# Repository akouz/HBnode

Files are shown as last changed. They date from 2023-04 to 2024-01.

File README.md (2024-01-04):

# HBnode
Microcontroller boards for [HBus](https://github.com/akouz/HBus) based on [AVR64DD32](https://www.microchip.com/en-us/product/avr64dd32). Form factor is the same as Arduino Pro Mini and Arduino Nano, while pinout made as close as possible. Firmware update made using on-board I2C EEPROM; custom bootloader occupies 1K bytes. 

[Programmer HEXloader.exe](https://github.com/akouz/HBnode/tree/main/AVR64DD32/Programmer/Software) can transfer compiled hex files from PC to EEPROM via Arduino UNO running [sketch HEXloader.ino](https://github.com/akouz/HBnode/tree/main/AVR64DD32/Programmer/Sketch). When a board used in HBus network, firmware can be updated remotely via HBus.

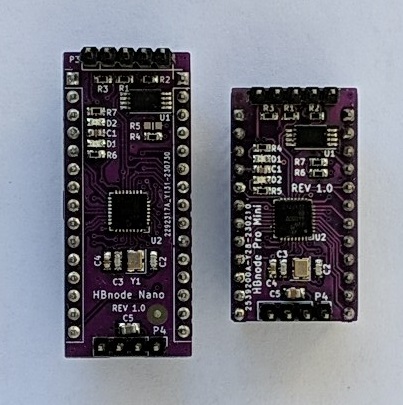
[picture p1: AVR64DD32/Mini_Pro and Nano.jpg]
Pro Mini and Nano


# How to program HBnode board:
1. Burn bootloader. 
   Plug PicKit4 to 4-pin connector, apply power to the board and burn [HBnode bootloader](https://github.com/akouz/HBnode/blob/main/AVR64DD32/Bootloader) using MPLAB.X IDE or MPLAB.X IPE.

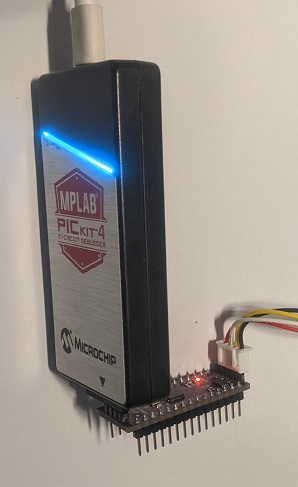
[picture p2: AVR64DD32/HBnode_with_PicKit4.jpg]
HBnode with PicKit4


2. Load HBus sketch.
   Connect HBnode to the [programmer](https://github.com/akouz/HBnode/tree/main/AVR64DD32/Programmer) and transfer selected sketch to the HBnode using [HEXLoader](https://github.com/akouz/HBnode/tree/main/AVR64DD32/Programmer/Software)
   
3. When a correct sketch is programmed to the HBnode, a new sketch can be loaded to the board via HBus using [NodeTest](https://github.com/akouz/HBus/tree/master/NodeTest)

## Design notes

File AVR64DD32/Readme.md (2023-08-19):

# HBnode AVR64DD32

Small modules based on AVR64DD32 are supposed to be used in [HBus](https://github.com/akouz/HBus) project instead of Arduino Pro Mini and Arduino Nano. They have the same size and similar pin-out, but differs by the following:

-- Program memory 64K instead of 32K.

-- Clock frequency 24 MHz instead of 16 MHz

-- Custom made bootloader dedicated for operation in HBus environment. HBus device based on HBnode can remotely upload a new firmare via HBus.

-- User monitor via I2C link and FT200XD test jig.

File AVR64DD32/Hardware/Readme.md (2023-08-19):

Boards HBnode Pro Mini and HBnode Nano are very similar.

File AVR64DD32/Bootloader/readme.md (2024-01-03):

# HBnode bootloader

Current rev 1.3.

It is compiled in MPLAB-X, compiler AVR-GCC v7.3.0. To fit bootloader into 1K compiler optimisation -s must be used.

Unlike other Arduino bootloaders, this bootloader copies content of the on-board EEPROM into AVR flash memory. EEPROM is supposed to be updated by application via HBus in small chunks.

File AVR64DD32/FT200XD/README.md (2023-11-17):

Test jig based on [FT200XD](https://ftdichip.com/products/ft200xd/) chip. Jig connected to HBnode 5-pin header P4 via 4-pin jack J2. P4 pin 1 not used; J2 pin 1 connects to P4 pin 2.

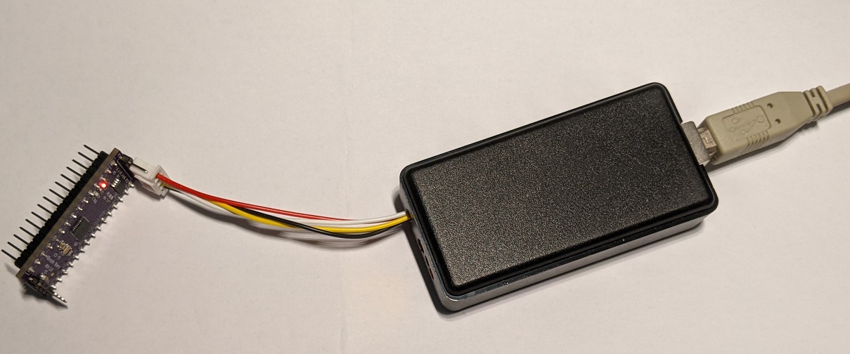
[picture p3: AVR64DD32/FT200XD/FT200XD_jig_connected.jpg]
Jig_connected


Use Windows Device Manager to configure FT200XD, it should operate as a virtual com port (VCP). Then use any hyperterminal to talk to HBnode monitor; [PuTTY](https://www.putty.org/) is recommended. 

After power-up HBus sketches usually sends to FT200XD a welcome screen, as shown in the following example:
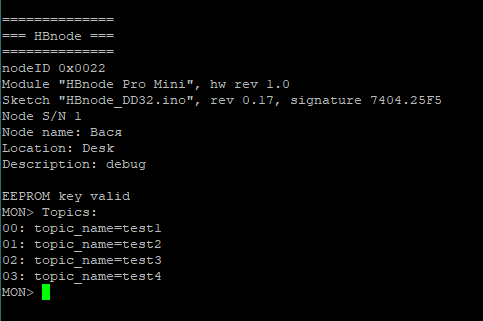
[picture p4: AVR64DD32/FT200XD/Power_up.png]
power_up


Using FT200XD and HBus sketch it is possible to to do the following:
* REV -- read hardware and sketch revisions
* SN -- read serial number
* xxxx SN -- assign a serial number xxxx to a blank board
* NODEID -- read HBus node ID 
* xxxx NODEID -- assign node ID xxxx to a blank board
* NAME -- read node name (optional)
* txt NAME -- assign node name txt
* LOCATION -- read node location  (optional)
* txt LOCATION -- assign node location txt
* DESCR -- read node description  (optional)
* txt DESCR -- assign node description txt
* addr len EERD -- read len bytes from I2C EEPROM starting at address addr
* addr len EECLR -- clear len bytes in the I2C EEPROM starting at address addr
* TOPIC -- read topic names and topic IDs; if topic value is valid it will be displayed too

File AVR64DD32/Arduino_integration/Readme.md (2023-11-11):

[DxCore](https://github.com/SpenceKonde/DxCore) project provides integration of AVR Dx microcontrollers with Arduino.  To use HBnode with Arduino, do the following:

  * Install DxCore to Arduino. Start Arduino IDE, in Tools/Board/Boards Manager find DxCore and install it. Current DxCore version is 1.5.11.
  * Open folder C:\Users\User\AppData\Local\Arduino15\packages\DxCore\hardware\megaavr\1.5.11
  * Replace file "boards.txt" with the file provided here
  
Use a demo sketch "Blink.ino" to test Arduino integration:

  * Copy sketch "Blink.ino" into a folder "Blink"
  * Start Arduino IDE
  * Select "Blink.ino" sketch
  * Select Tools/Board/DxCore/HBnode board
  * Compile sketch
  * Select Sketch/Export compiled Binary
  * Start HEXloader and navigate to the folder where "Blink.ino" sketch was placed
  * Select compiled hex file and send it to targed board EEPROM

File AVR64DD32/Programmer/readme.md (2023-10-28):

Programmer is used to download application code or compiled Arduino sketch into HBnode. Programmer is based on Arduino UNO, it runs the dedicated [programmer sketch HEXloader.ino](https://github.com/akouz/HBnode/tree/main/AVR64DD32/Programmer/Sketch) and it interacts with PC application named [HEXloader.exe](https://github.com/akouz/HBnode/tree/main/AVR64DD32/Programmer/Software).

This programmer is not able to program bootloader.

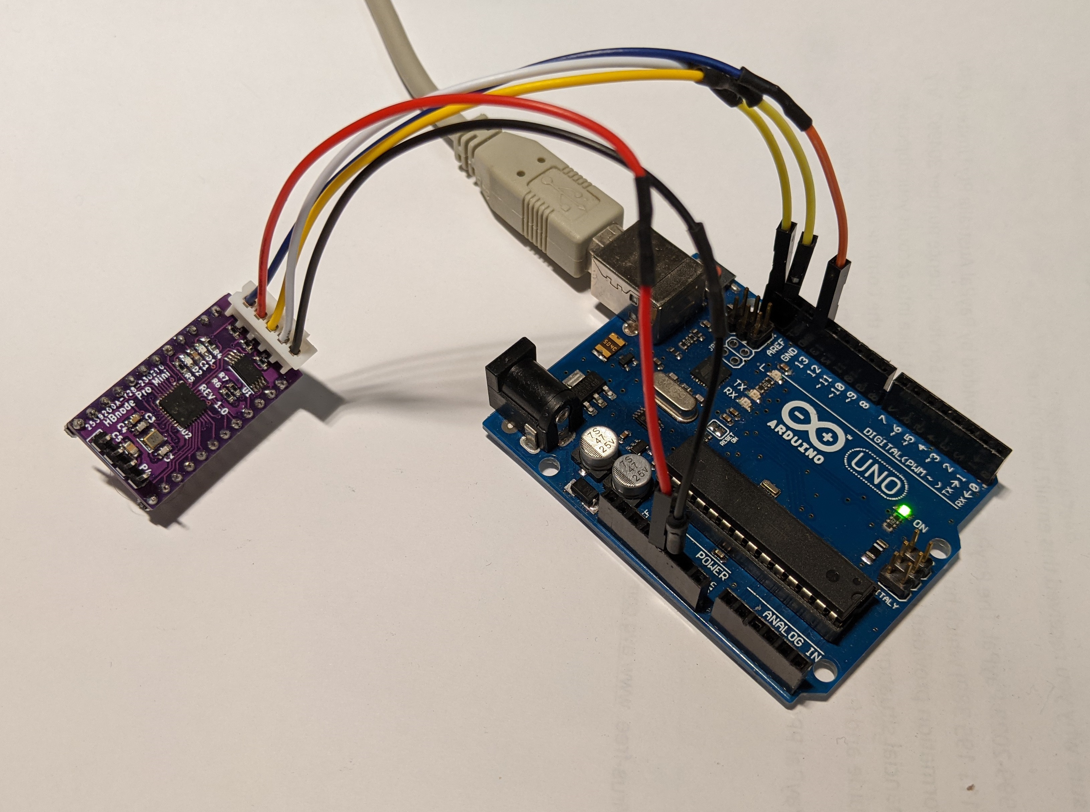
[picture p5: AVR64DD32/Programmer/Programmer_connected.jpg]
Programmer connected


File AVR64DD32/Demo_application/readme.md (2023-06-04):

# HBnode demo application

It is a simple demo application for HBnode, it flashes on-board red and green LEDs. It can be downloaded to HBnode using HEXloader.

Demo application is written in MPLAB-X using AVR-GCC compiler v7.3.0. In "Project Properties" select "Avr GCC/avr-ld/Memory Settings" and in the row "FLASH segment" enter ".text=0x200". It tells linker to place application after 1K because the lower 1K of program memory occupied by HBnode bootloader.

Alternatively, use a sketch compiled by Arduino as described in "Arduino_integration" chapter

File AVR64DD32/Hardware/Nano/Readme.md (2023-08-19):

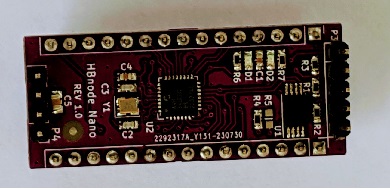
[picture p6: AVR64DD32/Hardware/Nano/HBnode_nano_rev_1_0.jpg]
Nano


Connector P4 for UPDI programmer/debugger. To program bootloader I used MPLAB X rev 6.05 and PicKit4.

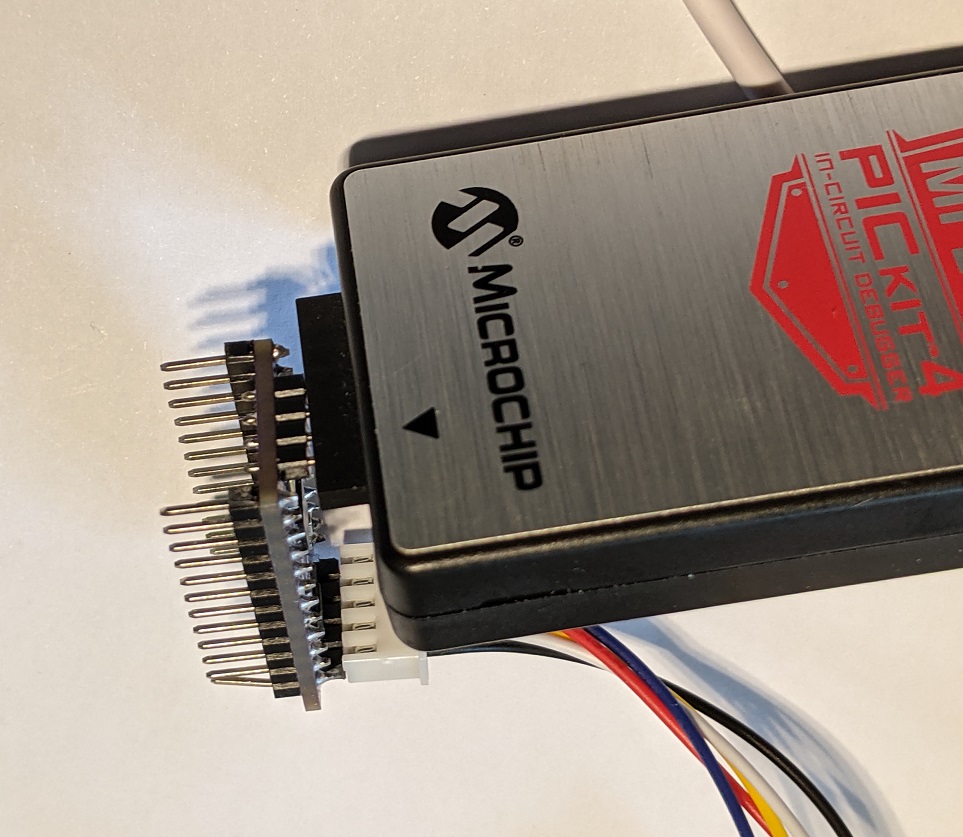
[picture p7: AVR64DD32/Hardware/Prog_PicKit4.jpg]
PicKit4


Connector P3 for a I2C programmer or for external monitor based on FT200XD. [I2C programmer](https://github.com/akouz/HBnode/tree/main/AVR64DD32/Programmer) writes application code into serial EEPROM U1, after reset bootloader copies EEPROM into program memory. Arduino UNO can be used as [I2C programmer](https://github.com/akouz/HBnode/tree/main/AVR64DD32/Programmer).

Programmer connected

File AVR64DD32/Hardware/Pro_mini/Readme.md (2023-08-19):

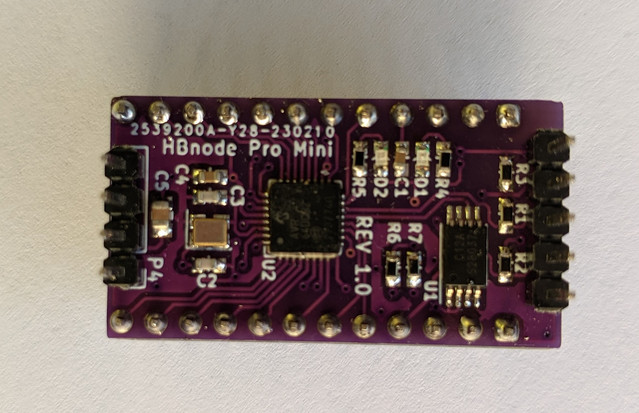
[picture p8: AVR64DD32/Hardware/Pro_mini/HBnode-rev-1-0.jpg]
Pro Mini


Connector P4 for UPDI programmer/debugger. To program bootloader I used MPLAB X rev 6.05 and PicKit4.

PicKit4

Connector P3 for a I2C programmer or for external monitor based on FT200XD. [I2C programmer](https://github.com/akouz/HBnode/tree/main/AVR64DD32/Programmer) writes application code into serial EEPROM U1, after reset bootloader copies EEPROM into program memory. Arduino UNO can be used as [I2C programmer](https://github.com/akouz/HBnode/tree/main/AVR64DD32/Programmer).

Programmer connected

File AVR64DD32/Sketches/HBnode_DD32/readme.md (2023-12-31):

Sketch rev 1.1  matches HBus rev 1.6. It can upload sketches via HBus using NodeTest rev 1.14 or later. 

Sketch implements HBus collision avoidance, CSMA/CA, based on CCL and EVSYS. The TxD output featured CSMA/CA is routed to port PC3, pin 9. This feature requires a hardware link between RX1 (port PC1, pin 7) and D2 (port PD6, pin 16) for proper operation.

Arduino IDE settings as shown:

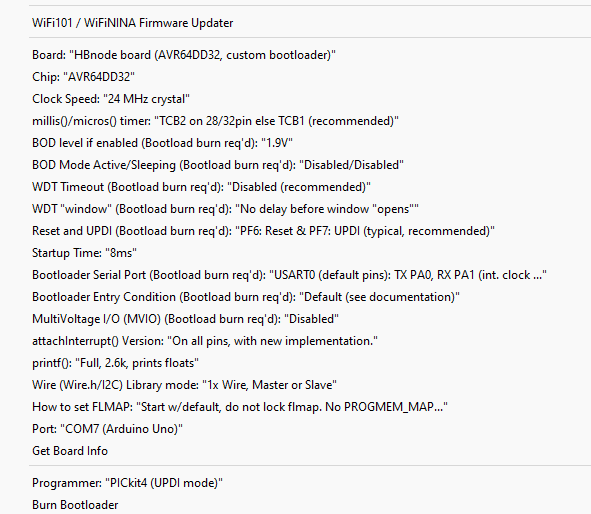
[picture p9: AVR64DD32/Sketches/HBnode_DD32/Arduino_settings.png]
settings


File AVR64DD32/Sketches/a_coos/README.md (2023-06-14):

Sketch to test [a_coos](https://github.com/akouz/a_coos) and i2c bitbang. Using bitbang, it prints to hyperterminal via a [test jig](https://github.com/akouz/HBnode/tree/main/AVR64DD32/FT200XD) based on [FT200XD](https://ftdichip.com/products/ft200xd/) chip.

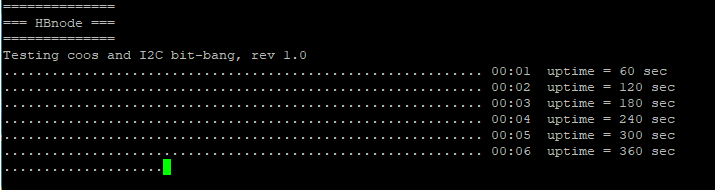
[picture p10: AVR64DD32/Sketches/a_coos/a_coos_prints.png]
prints


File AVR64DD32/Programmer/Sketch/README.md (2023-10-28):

# Sketch HEXloader

Sketch HEXloader for Arduino UNO used to download compiled files (sketches) into HBnode using
[HEXloader](https://github.com/akouz/HBnode/tree/main/AVR64DD32/Programmer/Software) application.

## General

HBnode employs AVR64DD32 and a serial EEPROM 24C512. HEXloader sketch writes code
received from the serial port into EEPROM while keeping AVR64DD32 in reset.
When application code copied into EEPROM, HEXloader  sketch releases AVR64DD32. The
HBnode bootloader in AVR64DD32 copies application code from EEPROM into flash
an passed control to the application code.

## Exchange with PC

Hardware serial port is used, baud rate 115200. PC sends ASCII strings, length
2...288 bytes. HEXloader  sketch reads strings and replies with ASCII strings too. In most
cases reply string consists of a single char and a terminator. String terminator
is any char with value less than 0x20. Blank char (' ', code 0x20) is ignored.
Input strings are not case sensitive.

The following commands from PC to HEXloader sketch are defined:
```
'R' - Read revision, HEXloader  sketch should reply "R" followed by its sketch revision.

'Q' - Query HBnode. HEXloader  sketch tries to read HBnode EEPROM. It replies '-' if EEPROM not
      detected, or '+' if EEPROM is present.

':' - Write a block of data in Intel HEX format to EEPROM. This message has the
      following structure:
      +-----+-----+------+------+------+---------+
      | ':' | Len | Addr | Type | Data | Cheksum |
      +-----+-----+------+------+------+---------+
      Example:
      :1001100060F00E94D70048E060E170E090E080E08D
      -- 10   - Len - data length 0x10 bytes
      -- 0110 - Addr - address 0x0110
      -- 00   - Type - data record
      -- 60 F0 0E 94 D7 00 48 E0  60 E1 70 E0 90 E0 80 E0  - Data
      -- 8D   - Checksum - two's complement of checksum LSB byte
      HEXloader  sketch should  reply '.' if writing succeeded, or 'x' in case
      of any error. If EEPROM disconnected it replies '-'

'!' - Write a decriptor for bootloader. This message has Intel HEX format.
      Its structure follows:
      +-----+------+------+------+---------+-----+---------+
      | '!' |  Len | Addr | Type | CodeLen | CRC | Cheksum |
      +-----+------+------+------+---------+-----+---------+
      Where:
      -- CodeLen - code length in EEPROM (starting from addr 0x0400)
      -- CRC - cyclic redundancy check for the valid EEPROM code
      If CRC matches then the following descriptor is written into EEPROM
      starting from address 0x0010:
      +------+------+------+------+-----------+-----------+-------+-------+
      | 0x55 | 0xAA | 0xC3 | 0x3C | CodeLen_H | CodeLen_L | CRC_H | CRC_L |
      +------+------+------+------+-----------+-----------+-------+-------+
      HEXloader  sketch should  reply '!' if writing succeeded, or 'x' in case
      of any error. If EEPROM disconnected it replies '-'

'L' - set active low level to HBnode reset line, reply is 'L'. Also reset crc
      and codelen counter.

'H' - set passive high level to HBnode reset line, reply is 'H'
```

## Writing to EEPROM

Write to EEPROM requires 5..10 ms to complete. At baud rate of 115200 bps, it
takes 86.8 us to transfer one byte, or 3.47 ms to transfer one chunk of 16 bytes
in HEX format.

EEPROM 24LC512 has internal data buffer size of 128 bytes. EEPROM exchange baud
rate is 200 kbps.

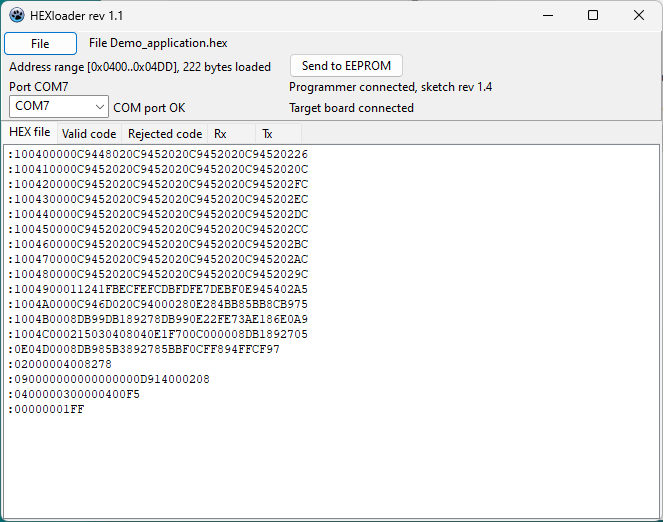
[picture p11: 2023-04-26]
AVR64DD32/Programmer/Software/HEXloader.png

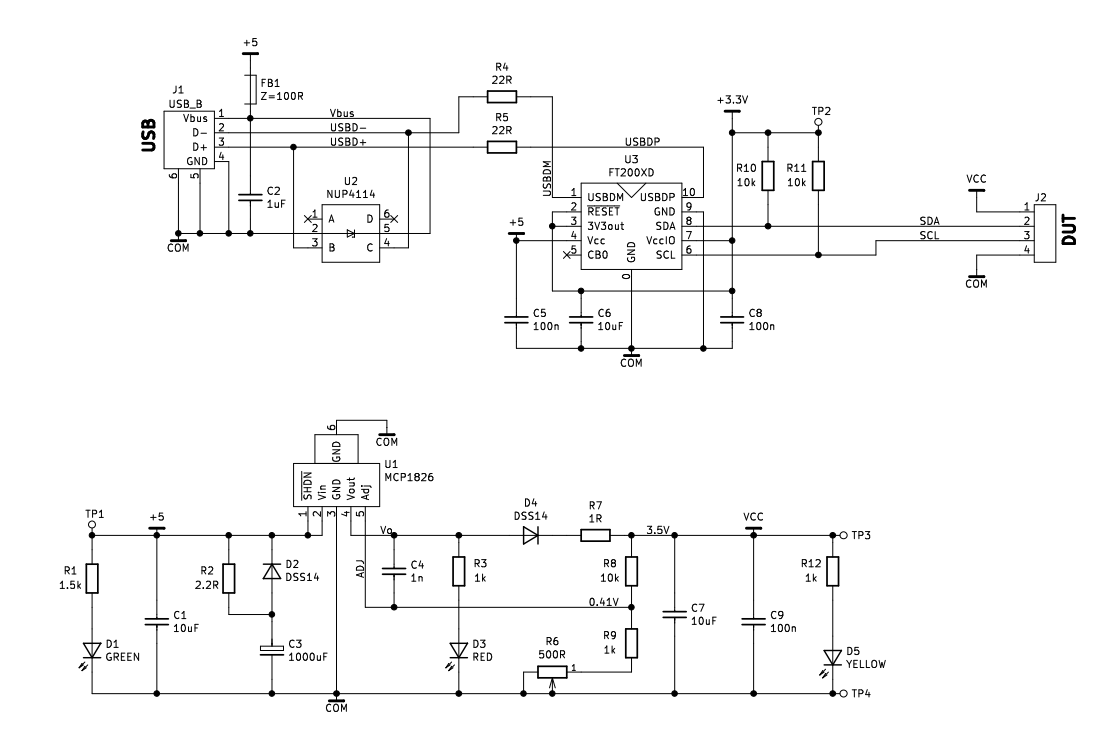
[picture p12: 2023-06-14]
AVR64DD32/FT200XD/FT200XD_jig.png

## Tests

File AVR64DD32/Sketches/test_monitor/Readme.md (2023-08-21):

A simple monitor works via FT200XD and a hyperterminal. Monitor uses Forth-like reverse polish notation, eg command goes last. Commands are not case sensitive.
The following commands implemented:
  * REV - prints sketch name and revision
  * SN - writes or reads serial number
  * NAME - writes or reads device name
  * LOCATION - writes or reads device location
  * CLK - read or write CLKCTRL registers

Serial number and text strings are stored in EEPROM.

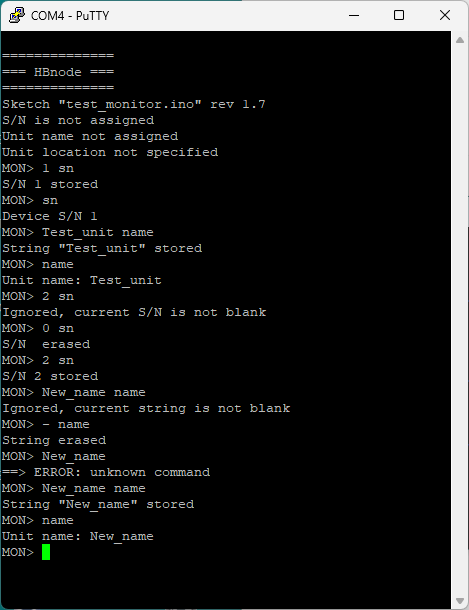
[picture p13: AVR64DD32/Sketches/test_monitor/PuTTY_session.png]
PuTTY session


CLK command added in rev 1.9:

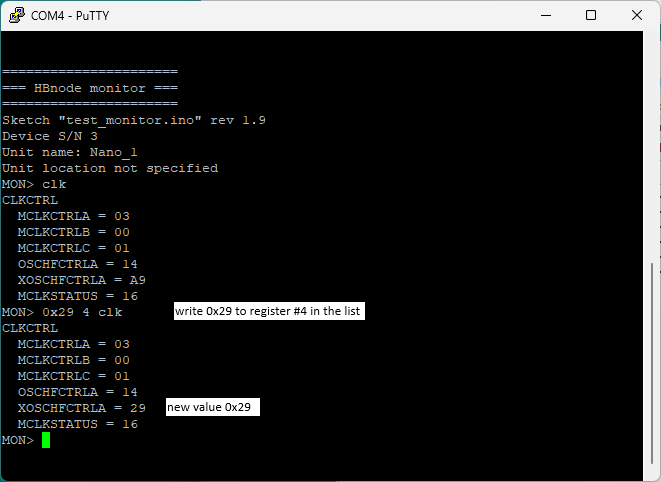
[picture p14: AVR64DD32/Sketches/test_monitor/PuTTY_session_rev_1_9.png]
CLK command


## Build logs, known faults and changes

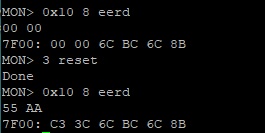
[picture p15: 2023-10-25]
AVR64DD32/debug_tmp/3_reset_mod.jpg

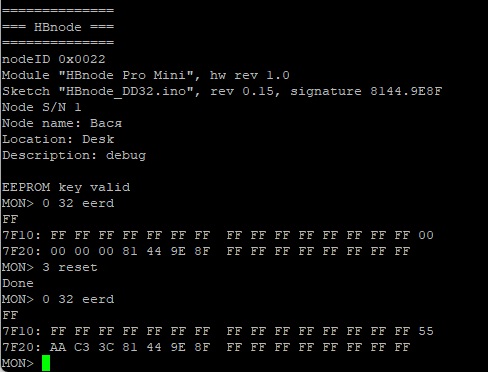
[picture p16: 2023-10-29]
AVR64DD32/debug_tmp/O2_eerd.jpg

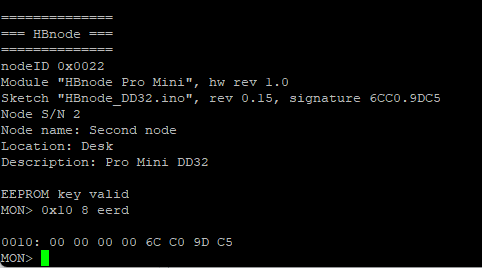
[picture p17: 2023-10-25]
AVR64DD32/debug_tmp/After_boot_1.png

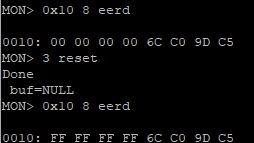
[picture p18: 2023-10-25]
AVR64DD32/debug_tmp/3_reset.jpg

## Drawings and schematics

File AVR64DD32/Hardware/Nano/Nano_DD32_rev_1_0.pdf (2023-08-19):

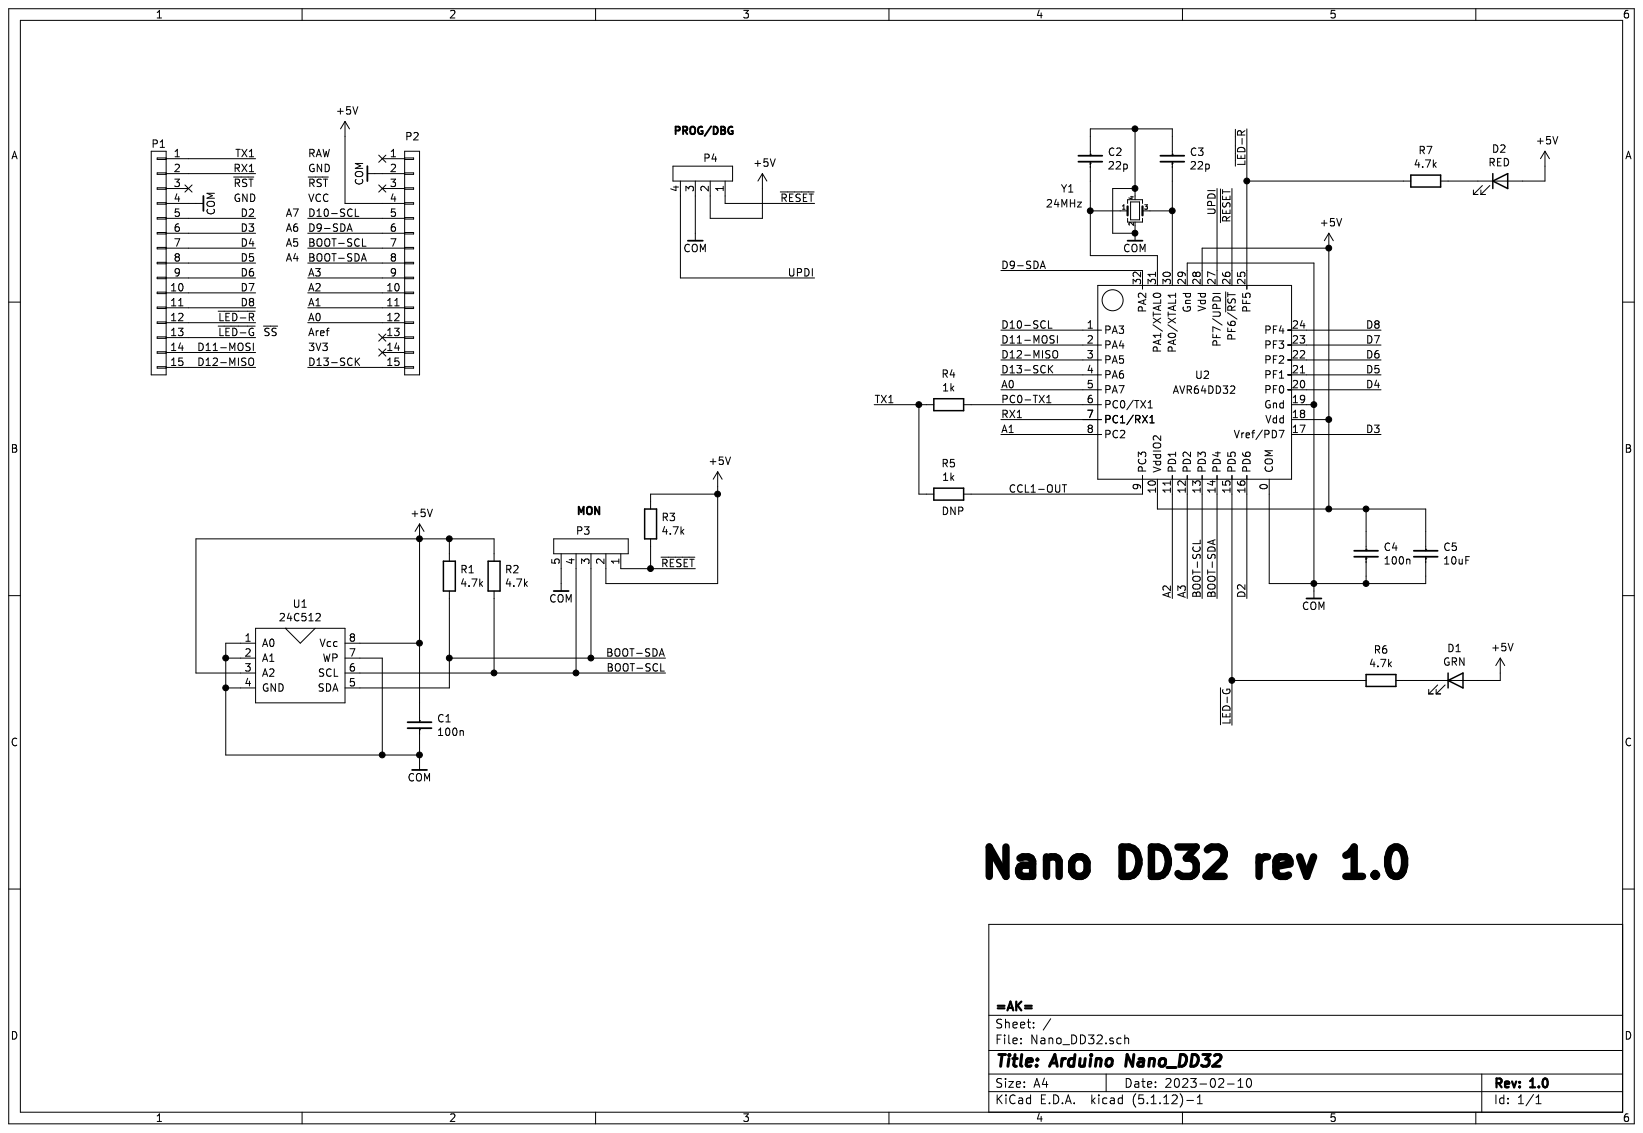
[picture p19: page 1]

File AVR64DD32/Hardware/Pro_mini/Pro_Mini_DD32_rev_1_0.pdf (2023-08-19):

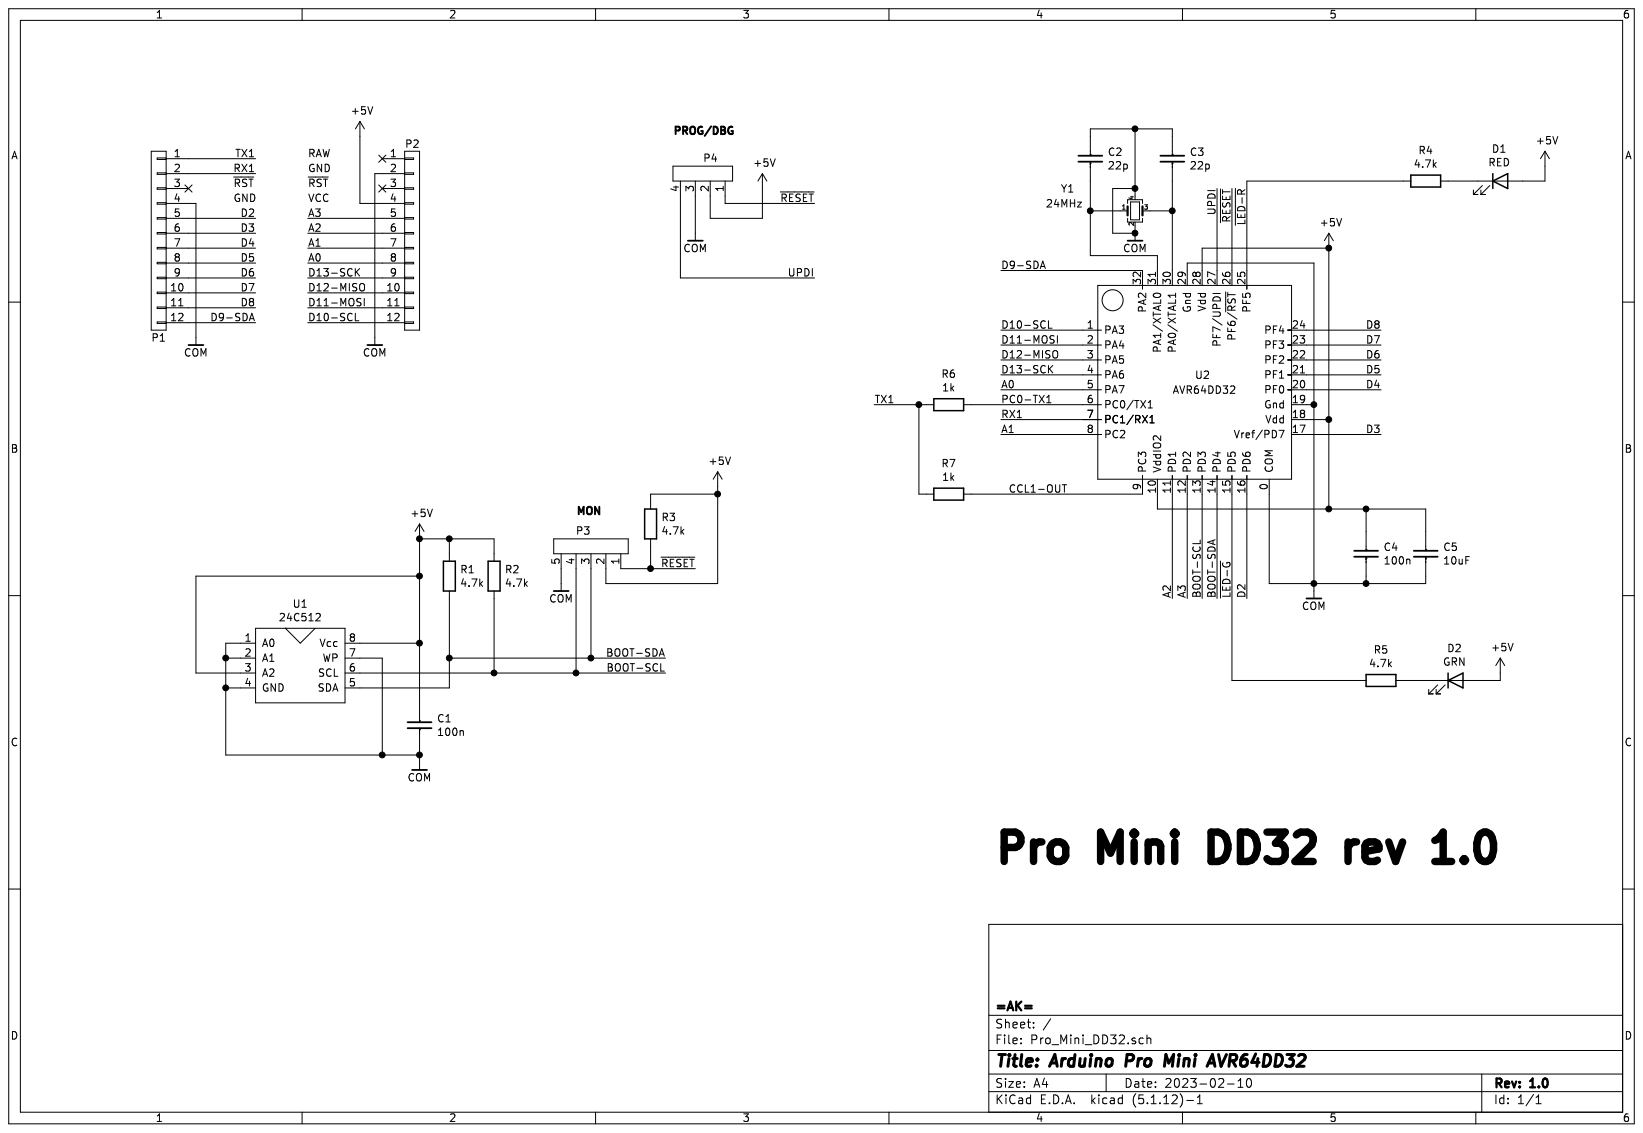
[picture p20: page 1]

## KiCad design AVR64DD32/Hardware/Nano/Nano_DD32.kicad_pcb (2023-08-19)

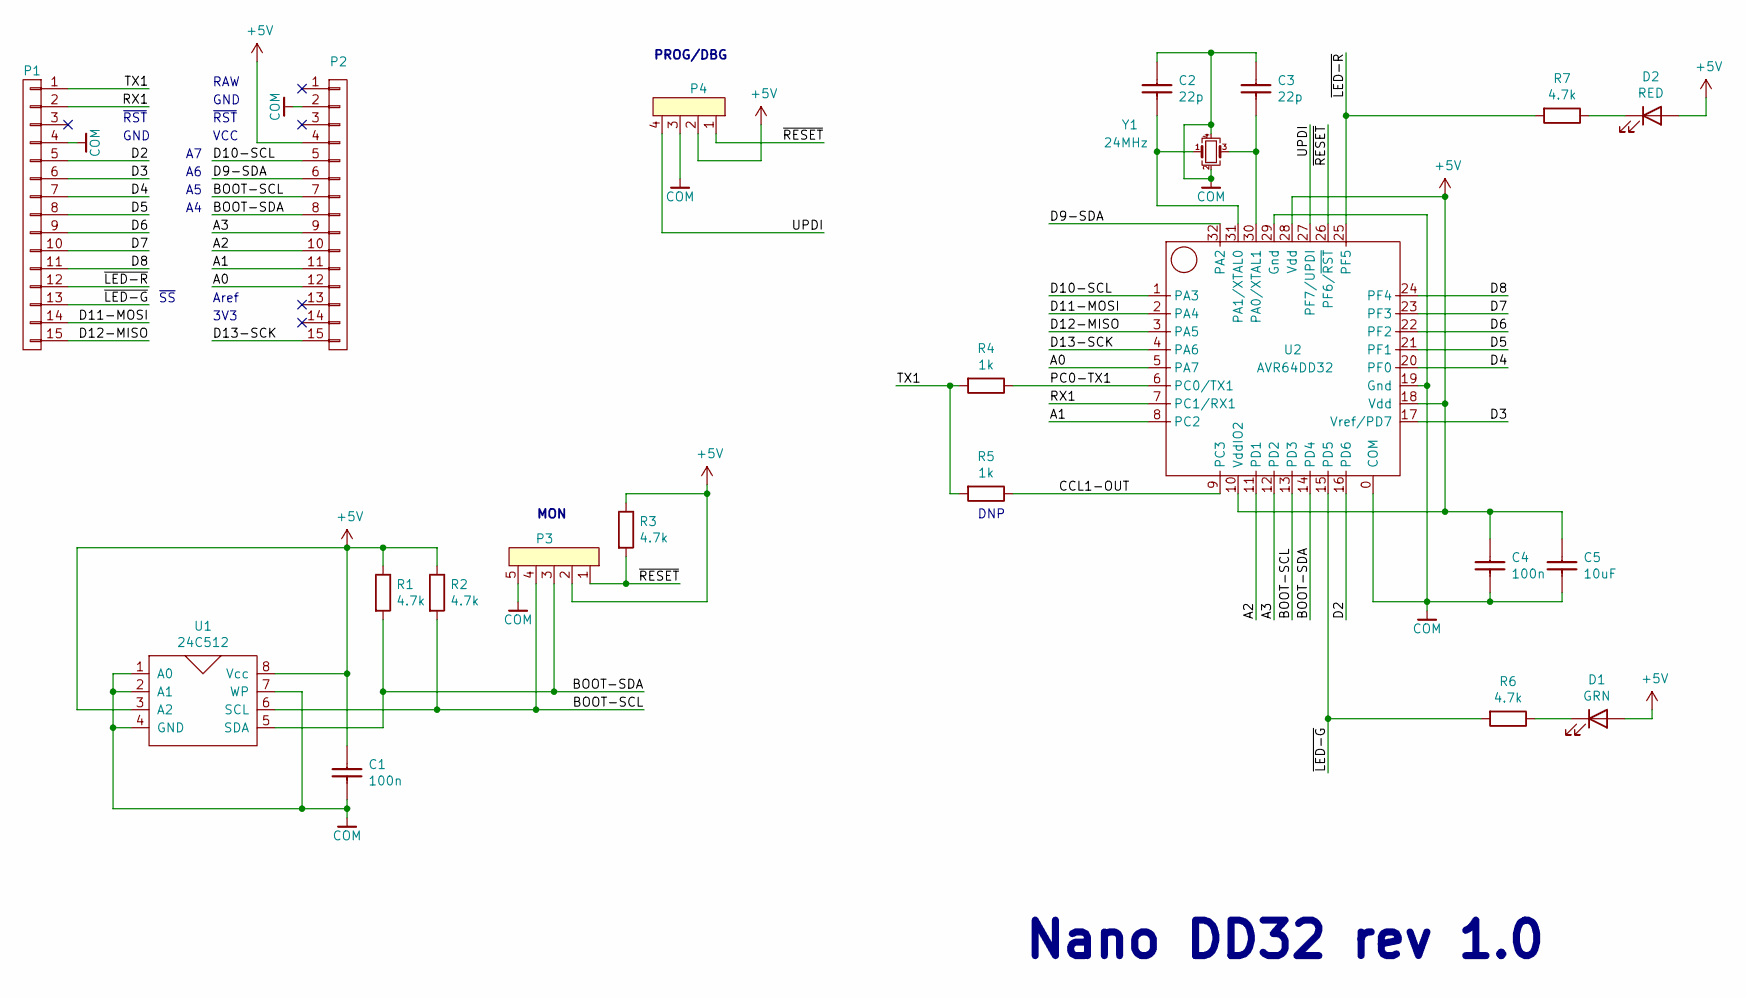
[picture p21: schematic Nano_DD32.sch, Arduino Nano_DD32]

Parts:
C1, C4: 100n; 0603
C2, C3: 22p; 0603
C5: 10uF; 0805
D1: GRN; 0603_LED
D2: RED; 0603_LED
P1, P2: CONN_01X15; PinHeader_1x15_P2.54mm_Vertical
P3: CONN_01X05
P4: CONN_01X04; PinHeader_1x04_P2.54mm_Vertical
R1, R2, R3, R6, R7: 4.7k; 0603
R4, R5: 1k; 0603
U1: 24C512; TSSOP-8_4.4x3mm_P0.65mm
U2: AVR64DD32; QFN-32-1EP_5x5mm_P0.5mm_EP3.1x3.1mm_pin0
Y1: 24MHz; Crystal_SMD_2520-4Pin_2.5x2.0mm

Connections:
+5V: C1.1, C4.1, C5.1, D1.2 (A), D2.2 (A), P2.4, P3.2, P4.2, R1.1, R2.1, R3.1, U1.3 (A2), U1.8 (Vcc), U2.10 (VddIO2), U2.18 (Vdd), U2.28 (Vdd)
/A0: P2.12, U2.5 (PA7)
/A1: P2.11, U2.8 (PC2)
/A2: P2.10, U2.11 (PD1)
/A3: P2.9, U2.12 (PD2)
/BOOT-SCL: P2.7, P3.4, R2.2, U1.6 (SCL), U2.13 (PD3)
/BOOT-SDA: P2.8, P3.3, R1.2, U1.5 (SDA), U2.14 (PD4)
/CCL1-OUT: R5.1, U2.9 (PC3)
/D2: P1.5, U2.16 (PD6)
/D3: P1.6, U2.17 (Vref/PD7)
/D4: P1.7, U2.20 (PF0)
/D5: P1.8, U2.21 (PF1)
/D6: P1.9, U2.22 (PF2)
/D7: P1.10, U2.23 (PF3)
/D8: P1.11, U2.24 (PF4)
/D9-SDA: P2.6, U2.32 (PA2)
/D10-SCL: P2.5, U2.1 (PA3)
/D11-MOSI: P1.14, U2.2 (PA4)
/D12-MISO: P1.15, U2.3 (PA5)
/D13-SCK: P2.15, U2.4 (PA6)
/PC0-TX1: R4.1, U2.6 (PC0/TX1)
/RX1: P1.2, U2.7 (PC1/RX1)
/TX1: P1.1, R4.2, R5.2
/UPDI: P4.4, U2.27 (PF7/UPDI)
/~LED-G: P1.13, R6.2, U2.15 (PD5)
/~LED-R: P1.12, R7.2, U2.25 (PF5)
/~RESET: P3.1, P4.1, R3.2, U2.26 (PF6/~RST)
COM: C1.2, C2.1, C3.1, C4.2, C5.2, P1.4, P2.2, P3.5, P4.3, U1.1 (A0), U1.2 (A1), U1.4 (GND), U1.7 (WP), U2.0 (COM), U2.19 (Gnd), U2.29 (Gnd), Y1.2, Y1.4
unnamed: C2.2, U2.31 (PA1/XTAL0), Y1.1
unnamed: C3.2, U2.30 (PA0/XTAL1), Y1.3
unnamed: D1.1 (K), R6.1
unnamed: D2.1 (K), R7.1

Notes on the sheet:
~RST
RAW
GND
VCC
PROG/DBG
MON
~SS
Nano DD32 rev 1.0
Aref
3V3
DNP

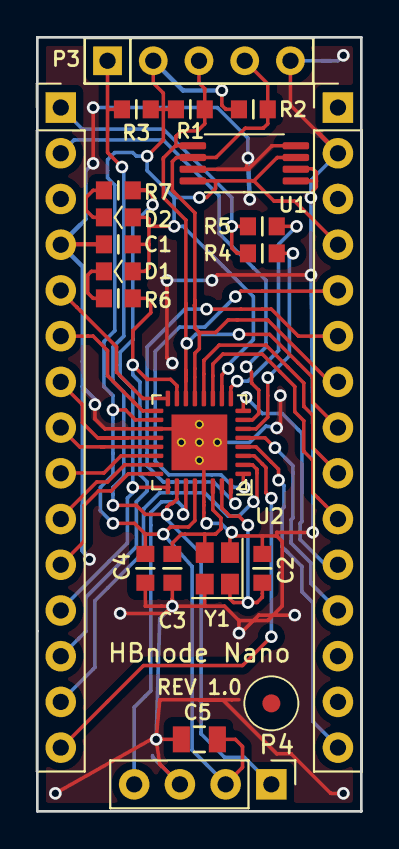
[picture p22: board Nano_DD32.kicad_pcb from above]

Board: 2 copper layers, 18.0 x 43.0 mm, 22 parts (0 on the bottom side), 32 nets.

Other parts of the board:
FID1: FIDUCIAL; Fiducial

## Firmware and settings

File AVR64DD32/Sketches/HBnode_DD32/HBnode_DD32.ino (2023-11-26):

/*
 * Sketch   HBus_DD32.ino - HBus implementation for HBnode
 * Author   A.Kouznetsov
 * Target   HBnode (AVRxxDD32)
 * Compiler Arduino with DxCore

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
THIS SOFTWARE IS PROVIDED BY THE COPYRIGHT HOLDERS AND CONTRIBUTORS "AS IS" AND 
ANY EXPRESS OR IMPLIED WARRANTIES, INCLUDING, BUT NOT LIMITED TO, THE IMPLIED 
WARRANTIES OF MERCHANTABILITY AND FITNESS FOR A PARTICULAR PURPOSE ARE 
DISCLAIMED. IN NO EVENT SHALL THE COPYRIGHT HOLDER OR CONTRIBUTORS BE LIABLE FOR 
ANY DIRECT, INDIRECT, INCIDENTAL, SPECIAL, EXEMPLARY, OR CONSEQUENTIAL DAMAGES 
(INCLUDING, BUT NOT LIMITED TO, PROCUREMENT OF SUBSTITUTE GOODS OR SERVICES; 
LOSS OF USE, DATA, OR PROFITS; OR BUSINESS INTERRUPTION) HOWEVER CAUSED AND ON 
ANY THEORY OF LIABILITY, WHETHER IN CONTRACT, STRICT LIABILITY, OR TORT 
(INCLUDING NEGLIGENCE OR OTHERWISE) ARISING IN ANY WAY OUT OF THE USE OF THIS
SOFTWARE, EVEN IF ADVISED OF THE POSSIBILITY OF SUCH DAMAGE.
 */

//##############################################################################
// Inc
//##############################################################################

#include "HBcommon.h"
#include "HBmonitor.h"
#include "HBcipher.h"
#include "HBus.h"
#include "HBcmd.h"
#include "HBmqtt.h"

//##############################################################################
// Var
//##############################################################################


//##############################################################################
// Func
//##############################################################################

/*
// ========================================
// From https://docs.arduino.cc/learn/programming/memory-guide
// ========================================
int freeRam() 
{
  extern int __heap_start,*__brkval;
  int v;
  return (int)&v - (__brkval == 0  ? (int)&__heap_start : (int) __brkval);  
}
*/
// ========================================
// Setup clock
// ========================================
void set_xtal_24MHz(void)
{
    CCP = IOREG;                  // unlock
    CLKCTRL.XOSCHFCTRLA = 0x19;   // XTAL 24 MHz, settle in 1K cycles
    while ((CLKCTRL.MCLKSTATUS & 0x10) == 0) // wait until XTAL is stable
    {
      Nop();
    }
    CCP = IOREG;                  // unlock
    CLKCTRL.MCLKCTRLA = 0x03;     // EXTCLK, no clockout
}
// ========================================
// Task 0 blinks green LED
// ========================================
void coos_task0(void)
{
//  static uchar cnt;
  while(1)
  {
    digitalWrite(GLED, LOW); 
    COOS_DELAY(100);      
    digitalWrite(GLED, HIGH); 
    COOS_DELAY(900);      
  }
}
// ========================================
// Broadcast topic values
// ========================================
// if node has permanent ID (eg if node configured) then every minute
// check next topic and broadcast its value if value is valid
void coos_task_broadcast_val(void)
{
    //hb_msg_t*  msg;
    static uchar idx = 0;    // topic index
    static uchar topic_id_refresh = 250;
    COOS_DELAY(5000);                                   // initial pause 5 sec
    HBmqtt.validate_topics();
    PRINT("MON> ");
    // -------------------------------
    // loop
    // -------------------------------
    while(1)
    {
        if (++topic_id_refresh >= 200)  // after power-up and once in a while
        {
            topic_id_refresh = 0;
            // annonce own topics at HBus
            while (HBmqtt.init_topic_id(node.ID) != OK)
            {
                COOS_DELAY(500);
            }
        }
        if ((node.boot_in_progr == 0) && (node.ID < 0xF000)) // if not a temporary ID
        {
            if ((HBmqtt.flag[idx].val_type) && (HBmqtt.flag[idx].topic_valid))  // broadcast only valid values
            {
                // msg = HBmqtt.publish_own_val(idx);
                HBmqtt.publish_own_val(idx);
            }
            if (++idx >= MAX_TOPIC)
            {
                idx = 0;
            }
        }
        //COOS_DELAY(1000);
        COOS_DELAY(30000);  // pause 30 sec
        COOS_DELAY(30000);  // pause 30 sec
    }
}
// ========================================
// Monitor task runs every 1 ms 
// ========================================
void coos_task_1ms(void)
{
  static uchar cnt = 0;
  while(1)
  {
    COOS_DELAY(1);
    if (i2cbb.EE_busy)
    {
      i2cbb.EE_busy--;  // count EEPROM delay  
    }  
    if (node.pause_cnt < 200)
    {
      node.pause_cnt++;
    }
    if (node.boot_in_progr)
    {
      node.boot_in_progr--;
    }
    if (++cnt >= 10)  // 10 ms
    {
      cnt = 0;
      HBcmd.tick10ms();
      if (OK == mon.Rx()) // when monitor command string ready
      {
        mon.parse();
        mon.exe();
      }
      if (node.rst_cnt)
      {
        node.rst_cnt--;
        if (node.rst_cnt == 0)  // must reset
        {
          PRINTLN(" resetting...");
          COOS_DELAY(10);
          CCP = IOREG;          // unlock
          RSTCTRL.SWRR = 1;     // software reset
          while(1)              // not required really...
          {
            Nop();    
          }
        }
      }
    }
  }
}  
// ========================================
// Clock prints current time every minute
// ========================================
void clock_func(void)
{
    char buf[0x10];
    sprintf(buf," %02d:%02d ", coos.hour(), coos.minute());
}
// ========================================
// Print bar
// ========================================
void ser_println_bar(uchar len)
{
    for (uchar i=0; i<len; i++)
    {
      Serial1.print('=');
    }      
    Serial1.println();
}
// ================================
void println_bar(uchar len)
{
    for (uchar i=0; i<len; i++)
    {
      PRINT('=');
    }      
    PRINTLN();
}
// ========================================
// Print header text to HBus
// ========================================
void print_hdr_txt(void)
{
    while (Serial1.available())
    {
        Serial1.read();
        delay(1);
    }
    Serial1.println();
    uchar len = strlen(PROJECT_NAME);
    ser_println_bar(len+8);
    Serial1.print("=== ");
    Serial1.print(PROJECT_NAME);
    Serial1.println(" ===");
    ser_println_bar(len+8);
    
    Serial1.print("NodeID 0x");
    Serial1.print(node.ID, HEX);
    if (vld_char(node.name_str[0]))
    {
      Serial1.print(", name: ");
      Serial1.print(node.name_str);
    }
    Serial1.println();

    Serial1.print("Module '");
    Serial1.print(ARDUINO_MODULE);
    Serial1.print("', h/w rev ");
    Serial1.print(HW_REV_MAJ);
    Serial1.print('.');
    Serial1.print(HW_REV_MIN);
    Serial1.print(", S/N ");
    if (node.sn[1])
    {
      Serial1.print(node.sn[1]);
      Serial1.print('.');
    }
    Serial1.println(node.sn[0]);

    Serial1.print("Sketch: '");
    Serial1.print(SKETCH_NAME);
    Serial1.print("', rev ");
    Serial1.print(SW_REV_MAJ);
    Serial1.print('.');
    Serial1.print(SW_REV_MIN);
    Serial1.print(", signature ");
    Serial1.print(node.prog_len, HEX);
    Serial1.print('.');
    Serial1.println(node.prog_crc, HEX);

    if (vld_char(node.location_str[0]))
    {
      Serial1.print("Location: ");
      Serial1.println(node.location_str);
    }
    if (vld_char(node.descr_str[0]))
    {
      Serial1.print("Description: ");
      Serial1.println(node.descr_str);
    }  
    Serial1.println(" ");
}

// ========================================
// Setup
// ========================================
void setup()
{  
  //CCP = IOREG;                // unlock
  //WDT.CTRLA = 10;             // WDT period 4 sec
  pinMode(RLED, OUTPUT);
  digitalWrite(RLED, HIGH);   // red LED off
  pinMode(GLED, OUTPUT);
  digitalWrite(GLED, LOW);    // green LED on
  set_xtal_24MHz();
  Serial1.begin(19200);
  CCL_config();
  EVSYS_config();
  print_hdr_txt();
  PRINTLN();
  PRINTLN();
//  PRINT("RSTFR = ");
//  PRINTLN((uchar)RSTCTRL.RSTFR);
  uchar len = strlen(PROJECT_NAME);
  println_bar(len+8);
  PRINT("=== ");
  PRINT(PROJECT_NAME);
  PRINTLN(" ===");
  println_bar(len+8);
  mon.print_id();   
  mon.print_rev();
  mon.print_sn();   
  mon.print_node_name();
  mon.print_node_location();
  mon.print_node_descr();
  HBcipher.get_EE_key();
  PRINTLN();
  PRINT("EEPROM key ");
  (HBcipher.valid)? PRINTLN("valid"): PRINTLN("invalid");
  PRINT("MON> "); // prompt
  node.rst_cnt = 0;
  coos.register_clock(clock_func);              // register clock function
  coos.register_task(coos_task0);               // register task 0   
  coos.register_task(coos_task_broadcast_val); 
  coos.register_task(coos_task_HBus_rxtx);
  coos.register_task(coos_task_1ms);  
  coos.start();                     // init registered tasks
}

// ========================================
// Main loop 
// ========================================
void loop()
{  
  coos.run();       // Coos scheduler 
  asm("wdr");       // reset watchdog
}
/* EOF */

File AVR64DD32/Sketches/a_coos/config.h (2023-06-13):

/*
 * File     config.h
 * Target   HBnode (AVRxxDD32)
 * Compiler Arduino with DxCore

 * (c) 2023 Alex Kouznetsov,  https://github.com/akouz/hbus
 *
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
 * THE SOFTWARE IS PROVIDED "AS IS", WITHOUT WARRANTY OF ANY KIND, EXPRESS OR
 * IMPLIED, INCLUDING BUT NOT LIMITED TO THE WARRANTIES OF MERCHANTABILITY,
 * FITNESS FOR A PARTICULAR PURPOSE AND NONINFRINGEMENT. IN NO EVENT SHALL THE
 * AUTHORS OR COPYRIGHT HOLDERS BE LIABLE FOR ANY CLAIM, DAMAGES OR OTHER
 * LIABILITY, WHETHER IN AN ACTION OF CONTRACT, TORT OR OTHERWISE, ARISING FROM,
 * OUT OF OR IN CONNECTION WITH THE SOFTWARE OR THE USE OR OTHER DEALINGS IN THE
 * SOFTWARE.
 */

#ifndef __CONFIG_H
#define	__CONFIG_H

//##############################################################################
// Inc
//##############################################################################

#include <coos.h>

//##############################################################################
// Def
//##############################################################################

// ==================================
// Software revision
// ==================================
#define SW_REV_MAJ    1
#define SW_REV_MIN    0



#ifndef __UCHAR_DEFINED__
  #define __UCHAR_DEFINED__
  typedef unsigned char uchar;
  typedef signed   char schar;
  typedef unsigned int  uint;
  typedef unsigned long ulong;
  typedef signed   long slong;
#endif

#ifndef NULL  
    #define NULL 0  
#endif
  
#define OK      0
#define ERR     0xEE  
#define CR      13
#define LF      10  
  
#define BIT0    0x01  
#define BIT1    0x02
#define BIT2    0x04  
#define BIT3    0x08  
#define BIT4    0x10  
#define BIT5    0x20  
#define BIT6    0x40  
#define BIT7    0x80  
  
#define NOP()   asm("nop") 

enum{
    TICK_1000US   = 0,    // 1 ms in average because of corrections made in millis(),  
                          // see https://www.best-microcontroller-projects.com/arduino-millis.html
    TICK_1024US   = 1     // 1.024 ms
};
#define TICK   TICK_1000US  // select tick
  
#define SET_SCL PORTD.DIRCLR = BIT3   // input
#define CLR_SCL PORTD.DIRSET = BIT3   // output
#define SET_SDA PORTD.DIRCLR = BIT4
#define CLR_SDA PORTD.DIRSET = BIT4   
#define SDA_IN (PORTD.IN & BIT4)

//#define SET_LED PORTF.DIRSET = BIT5;  PORTF.OUTCLR = BIT5
//#define CLR_LED PORTF.OUTSET = BIT5  
  
#define EE_WR_ADDR  0xA8        // A0=0, A1=0, A2=1  
#define EE_RD_ADDR  0xA9        // A0=0, A1=0, A2=1  
#define FT_WR_ADDR  0x44        // 7-bit addr 0x22
#define FT_RD_ADDR  0x45  

#define RED_LED  PIN_PF5
#define GRN_LED  PIN_PD5

#define RLED  RED_LED
#define GLED  GRN_LED

#define TOGGLE_GLED PORTD.OUT ^= BIT5

//##############################################################################
// Inc
//##############################################################################

#include "i2c_bitbang.h"


#endif	/* __CONFIG_H */

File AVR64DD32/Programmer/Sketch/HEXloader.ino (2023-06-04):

/*  Project:  HEXloader
 *  Author:   A.Kouznetsov
 *  File:     HEXloader.ino
 */

//##############################################################################
// Inc
//##############################################################################

#include <Firmata.h>
#include <Wire.h>
#include "description.h"
#include "RxTx.h"
#include "EEPROM.h"

//##############################################################################
// Def
//##############################################################################

#define MAX_BBUF  4

//##############################################################################
// Var
//##############################################################################

RxTx rxtx;
HB_eeprom ee;
binbuf_t  bbuf;

//##############################################################################
// Func
//##############################################################################

//================================
// Process received buffer
//================================
uchar process_rxbuf(void)
{
  uchar res = ERR;
  char c;
  if (rxtx.rxlen)
  {
    switch(rxtx.rxbuf[0])
    {
      // -------------------------
      case 'H':
      digitalWrite(RST_PIN, HIGH);
      Serial.print('H');
      Serial.print(char(0));
      break;
      // -------------------------
      case 'L':
      digitalWrite(RST_PIN, LOW);
      ee.crc = 0xFFFF;   // be ready to receive hex code
      rxtx.codelen = 0;
      Serial.print('L');
      Serial.print(char(0));
      break;
      // -------------------------
      case 'Q':
        c = (ee.connected())? '-' : '+';
        Serial.print(c);
        Serial.print(char(0));
        res = OK;
        break;
      // -------------------------
      case 'R':
        res = rxtx.reply_rev();
        break;
      // -------------------------
      case ':':
        res = rxtx.HEX_to_bin(&bbuf);
        if (res == DONE)
        {
          if (ee.connected())   // if Ack high
          {
            Serial.print('-');  // EEPROM disconnected
          }
          else
          {
            res = ee.write_buf(&bbuf);
            switch(res)
            {
              case 0:
                Serial.print('.'); break; // success
              case 1:
                Serial.print('-'); break; // EEPROM disconnected
              default:
                Serial.print('x'); break; // other errors
            }
          }
          Serial.print(char(0));
        } // else 'x' sent
        break;
        // -------------------------
        case '!':
          res = rxtx.HEX_to_bin(&bbuf);
          if (res == DONE)
          {
            if (ee.connected())   // if Ack high
            {
              Serial.print('-');  // EEPROM disconnected
            }
            else
            {
              res = ee.write_descr(&bbuf);
              switch(res)
              {
                case 0:
                  Serial.print('!'); break; // success
                case 1:
                  Serial.print('-'); break; // EEPROM disconnected
                case INVALID:
                  Serial.print('C'); break; // CRC mismatch
                default:
                  Serial.print('x'); break; // other errors
              }
            }
            Serial.print(char(0));
          } // else 'x' sent
          break;
      // -------------------------
      default:
        break;
    }
    if (res != NOT_READY)
    {
      rxtx.rxlen = 0;   // clear rx buffer
    }
  }
  return res;
}
//#####################################################
// Setup
//#####################################################
void setup()
{
  Serial.begin(115200);             // serial baud rate 115.2 kbps
  pinMode(LED_BUILTIN, OUTPUT);
  digitalWrite(LED_BUILTIN,LOW);
  pinMode(RST_PIN, OUTPUT);
  digitalWrite(RST_PIN, LOW);       // by default appy reset to HBus node
  Serial.println("");
  Serial.println("=================================");
  Serial.println("=== HBus HEXloader programmer ===");
  Serial.println("=================================");
  rxtx.reply_rev();      		// promptly print revisions
  digitalWrite(RST_PIN, HIGH); 		// release target 
}
//#####################################################
// Run
//#####################################################
void loop()
{
  // ----------------------------
  // receive chars
  // ----------------------------
  while (Serial.available())  // If anything comes in Serial (USB),
  {
    if (rxtx.add_rx_char(Serial.read()) == DONE) // string ready
    {
      process_rxbuf();    // execute received command
      break;
    }
  }
}

/* EOF */
